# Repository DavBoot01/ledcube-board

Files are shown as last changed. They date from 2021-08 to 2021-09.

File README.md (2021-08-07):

# ledcube8x8x8-board

This is a Kicad project for a Led Cube 8x8x8 controller board.

### Tags

- FPGA/CPLD
- ESP32
- Led controller

### Used Library and Footprint

- DigiKey: https://github.com/Digi-Key/digikey-kicad-library
- LM1085: https://app.ultralibrarian.com/details/15DE1302-103F-11E9-AB3A-0A3560A4CCCC/Texas-Instruments/LM1085IS-12-NOPB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
- SN74LVCC3245APWR: https://www.snapeda.com/parts/SN74LVCC3245APWR/TEXAS%20INSTRUMENTS%20(VA)/view-part/?ref=digikey
- B8B-PH-SM4-TB: https://www.snapeda.com/parts/B8B-PH-SM4-TB(LF)(SN)/JST%20Sales/view-part/?ref=digikey
- ESP32-DEVKITC-32D: https://www.snapeda.com/parts/ESP32-DEVKITC-32D/Espressif%20Systems/view-part/
- (SLOT uSD) WM6357CT-ND: https://www.snapeda.com/parts/104031-0811/Molex/view-part/?ref=digikey
- IP4220CZ6F: https://www.snapeda.com/parts/IP4220CZ6/NXP%20Semiconductors/view-part/?ref=digikey

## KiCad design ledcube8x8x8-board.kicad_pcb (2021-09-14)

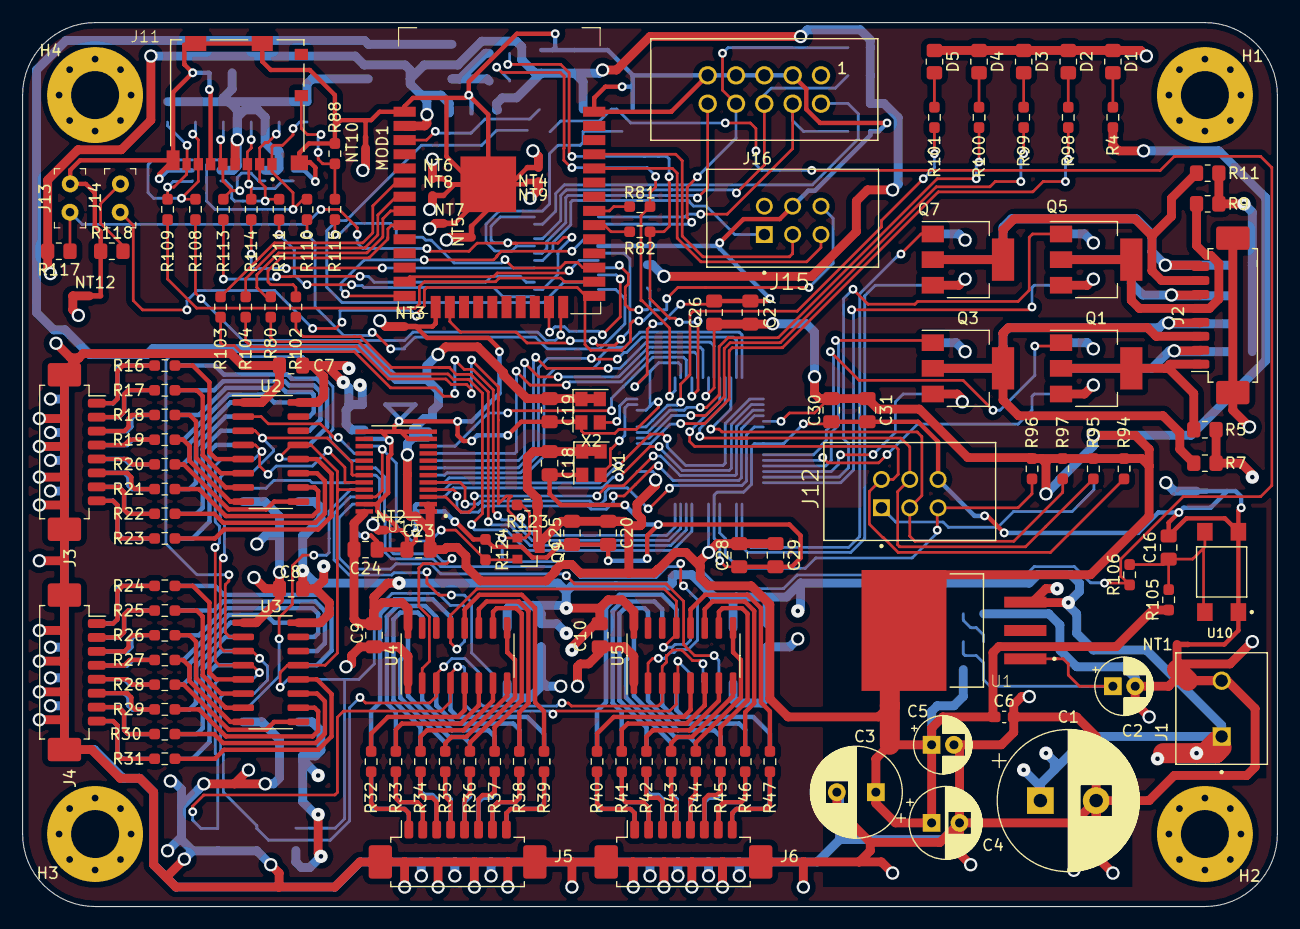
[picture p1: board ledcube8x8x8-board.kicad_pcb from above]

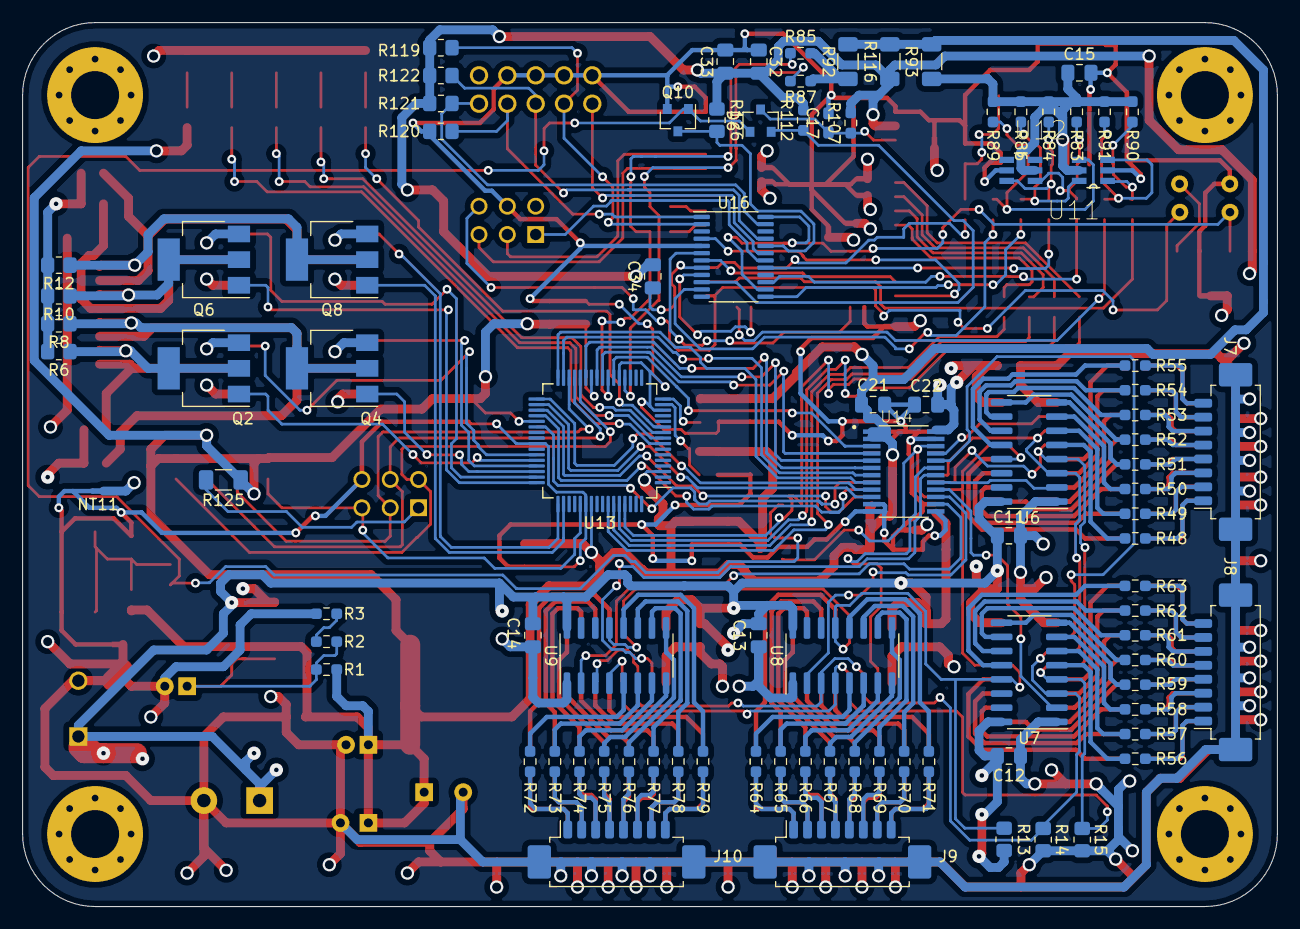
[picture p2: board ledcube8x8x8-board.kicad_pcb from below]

Board: 4 copper layers, 112.5 x 79.2 mm, 227 parts (92 on the bottom side), 239 nets.

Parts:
C1: 1000uF; CP_Radial_D12.5mm_P5.00mm
C2, C5: 10uF; CP_Radial_D5.0mm_P2.00mm
C3: 150uF; CP_Radial_D8.0mm_P3.50mm
C4: 100uF; CP_Radial_D6.3mm_P2.50mm
C6, C17: 1uF; C_0603_1608Metric_Pad1.08x0.95mm_HandSolder
C7, C8, C9, C10, C11, C12, C13, C14, C16, C21, C22, C23, C24, C28, C29, C30, C31, C32: 100nF; C_0805_2012Metric_Pad1.18x1.45mm_HandSolder
C15, C34: 4.7uF; C_0805_2012Metric_Pad1.18x1.45mm_HandSolder
C18, C19, C20, C25, C26, C27: 10nF; C_0805_2012Metric_Pad1.18x1.45mm_HandSolder
C33: 22uF; C_0805_2012Metric_Pad1.18x1.45mm_HandSolder
D1, D3: GREEN; R_0805_2012Metric_Pad1.20x1.40mm_HandSolder
D2: RED; R_0805_2012Metric_Pad1.20x1.40mm_HandSolder
D4, D5: ORANGE; R_0805_2012Metric_Pad1.20x1.40mm_HandSolder
D6: BAT54A; SOT-23
H1, H2, H3, H4: MountingHole_Pad; MountingHole_4.3mm_M4_Pad_Via
J1: 282836-2; CONN_282836-2
J2, J3, J4, J5, J6, J7, J8, J9, J10: molex_53261-0871; Molex_PicoBlade_53261-0871_1x08-1MP_P1.25mm_Horizontal
J11: 104031-0811; MOLEX_104031-0811
J12, J15: 30306-6002HB; 3M_30306-6002HB
J13, J14: hedear; PinHeader_1x2_P2.54mm
J16: 61201021621
MOD1: ESP32-WROOM-32; ESP32-WROOM-32D
NT1, NT2, NT3, NT4, NT5, NT6, NT7, NT8, NT9, NT10, NT11, NT12: Net-Tie_2; NetTie-2_SMD_Pad0.5mm
Q1, Q2, Q3, Q4, Q5, Q6, Q7, Q8: Q_NMOS_GDSD; SOT-223
Q9, Q10: Q_PMOS_GSD; SOT-23
R1: 121; R_0603_1608Metric_Pad0.98x0.95mm_HandSolder
R2: 42.2; R_0603_1608Metric_Pad0.98x0.95mm_HandSolder
R3: 56.2; R_0603_1608Metric_Pad0.98x0.95mm_HandSolder
R4, R98, R99, R100, R101: 1K; R_0603_1608Metric_Pad0.98x0.95mm_HandSolder
R5, R6, R7, R8, R9, R10, R11, R12, R13, R14, R15, R117, R118, R119, R120, R121, R122, R126: 10K; R_0805_2012Metric_Pad1.20x1.40mm_HandSolder
R16, R17, R18, R19, R20, R21, R22, R23, R24, R25, R26, R27, R28, R29, R30, R31, R32, R33, R34, R35, R36, R37, R38, R39, R40, R41, R42, R43, R44, R45, R46, R47, R48, R49, R50, R51, R52, R53, R54, R55, R56, R57, R58, R59, R60, R61, R62, R63, R64, R65, R66, R67, R68, R69, R70, R71, R72, R73, R74, R75, R76, R77, R78, R79: 100; R_0603_1608Metric_Pad0.98x0.95mm_HandSolder
R80, R81, R82, R102, R103, R104, R106, R108, R109, R110, R111, R113, R114, R115: 0R; R_0603_1608Metric_Pad0.98x0.95mm_HandSolder
R83, R84, R86, R88, R89, R90, R91, R94, R95, R96, R97, R105, R107, R123, R124: 10K; R_0603_1608Metric_Pad0.98x0.95mm_HandSolder
R85, R87: 2K7; R_0603_1608Metric_Pad0.98x0.95mm_HandSolder
R92, R93, R116, R125: 0R; R_1206_3216Metric_Pad1.30x1.75mm_HandSolder
R112: 47K; R_0603_1608Metric_Pad0.98x0.95mm_HandSolder
U1: LM1085IS-12; TO254P1524X483-4N
U2, U3, U4, U5, U6, U7, U8, U9: STP08CP05MTR; SOIC-16_3.9x9.9mm_P1.27mm
U10: TL3305AF260QG; SW_TL3305AF260QG
U11, U12: IP4220CZ6; SOT95P275X110-6N
U13: XC9572XL-VQ64; TQFP-64_10x10mm_P0.5mm
U14, U15: SN74LVCC3245APWR; SOP65P640X120-24N
U16: TS3A27518EPW; TSSOP-24_4.4x7.8mm_P0.65mm
X1: ASE-40MHz; Oscillator_SMD_Abracon_ASE-4Pin_3.2x2.5mm
X2: ASE-25MHz; Oscillator_SMD_Abracon_ASE-4Pin_3.2x2.5mm

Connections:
/DATA_LED1: U2.2, U14.21
/DATA_LED2: U3.2, U14.20
/DATA_LED3: U4.2, U14.19
/DATA_LED4: U5.2, U14.18
/DATA_LED5: U6.2, U14.17
/DATA_LED6: U7.2, U14.16
/DATA_LED7: U8.2, U14.15
/DATA_LED8: U9.2, U14.14
/LAYER_SEL1: Q1.1, U13.43
/LAYER_SEL2: Q2.1, U13.44
/LAYER_SEL3: Q3.1, U13.45
/LAYER_SEL4: Q4.1, U13.46
/LAYER_SEL5: Q5.1, U13.47
/LAYER_SEL6: Q6.1, U13.48
/LAYER_SEL7: Q7.1, U13.49
/LAYER_SEL8: Q8.1, U13.50
/VCC_3V3: C3.1, C4.1, C5.1, C6.1, C18.1, C19.1, C20.1, C21.2, C23.2, C25.1, C26.1, C27.1, C28.1, C29.1, C30.1, C31.1, Q9.3, R1.1, R4.1, R92.2, R93.2, R94.1, R95.1, R96.1, R97.1, R105.1, R116.2, R123.1, R125.1, U1.4, U13.3, U13.26, U13.37, U13.55, U14.1, U14.2, U15.1, U15.2, X1.1, X1.4, X2.1, X2.4
/VCC_5V0: C1.1, C7.1, C8.1, C9.1, C10.1, C11.1, C12.1, C13.1, C14.1, C22.2, C24.2, J1.1, R5.2, R6.2, R7.2, R8.2, R9.2, R10.2, R11.2, R12.2, R13.1, U1.3, U2.16, U3.16, U4.16, U5.16, U6.16, U7.16, U8.16, U9.16, U14.24, U15.24
/layer_led_mux.sch/CLK: R14.1, U2.3, U3.3, U4.3, U5.3, U6.3, U7.3, U8.3, U9.3, U15.19
/layer_selector.sch/LAYER_SEL1: J2.1, Q1.2, Q1.4, R5.1
/layer_selector.sch/LAYER_SEL2: J2.2, Q2.2, Q2.4, R6.1
/layer_selector.sch/LAYER_SEL3: J2.3, Q3.2, Q3.4, R7.1
/layer_selector.sch/LAYER_SEL4: J2.4, Q4.2, Q4.4, R8.1
/layer_selector.sch/LAYER_SEL5: J2.5, Q5.2, Q5.4, R9.1
/layer_selector.sch/LAYER_SEL6: J2.6, Q6.2, Q6.4, R10.1
/layer_selector.sch/LAYER_SEL7: J2.7, Q7.2, Q7.4, R11.1
/layer_selector.sch/LAYER_SEL8: J2.8, Q8.2, Q8.4, R12.1
/pl.sch/CLK_25M: U13.16, X2.3
/pl.sch/CLK_40M: U13.15, X1.3
/pl.sch/DATA_CLK_3V3: U13.38, U15.5
/pl.sch/DATA_LE_3V3: U13.36, U15.4
/pl.sch/DATA_LE_5V0: R15.1, U2.4, U3.4, U4.4, U5.4, U6.4, U7.4, U8.4, U9.4, U15.20
/pl.sch/DATA_ROW1_3V3: U13.22, U14.3
/pl.sch/DATA_ROW2_3V3: U13.24, U14.4
/pl.sch/DATA_ROW3_3V3: U13.25, U14.5
/pl.sch/DATA_ROW4_3V3: U13.27, U14.6
/pl.sch/DATA_ROW5_3V3: U13.31, U14.7
/pl.sch/DATA_ROW6_3V3: U13.32, U14.8
/pl.sch/DATA_ROW7_3V3: U13.33, U14.9
/pl.sch/DATA_ROW8_3V3: U13.34, U14.10
/pl.sch/GPIO0: R80.1, U13.58
/pl.sch/GPIO1: R102.1, U13.59
/pl.sch/GPIO2: R103.1, U13.60
/pl.sch/GPIO3: R104.1, U13.61
/pl.sch/I2C_SCL: R81.1, R87.2, U13.20
/pl.sch/I2C_SDA: R82.1, R85.2, U13.23
/pl.sch/LED_G: R99.1, U13.9
/pl.sch/LED_O1: R100.1, U13.10
/pl.sch/LED_O2: R101.1, U13.11
/pl.sch/LED_R: R98.1, U13.8
/pl.sch/TCK: J12.3, R97.2, U13.30
/pl.sch/TDI: J12.2, R94.2, U13.28
/pl.sch/TDO: J12.5, R96.2, U13.53
/pl.sch/TMS: J12.4, R95.2, U13.29
/pl.sch/~DATA_OE_3V3: U13.35, U15.3
/pl.sch/~DATA_OE_5V0: R13.2, U2.13, U3.13, U4.13, U5.13, U6.13, U7.13, U8.13, U9.13, U15.21
/pl.sch/~OE: Q9.2, R124.1, U14.22, U15.22
/pl.sch/~SYS_RST: D6.1, Q9.1, Q10.1, R106.1, R123.2
/ps.sch/ESP_GPIO0: MOD1.8, R80.2
/ps.sch/ESP_GPIO1: MOD1.9, R102.2
/ps.sch/ESP_GPIO2: MOD1.6, R103.2
/ps.sch/ESP_GPIO3: MOD1.7, R104.2
/ps.sch/ESP_I2C_SCL: MOD1.31, R81.2
/ps.sch/ESP_I2C_SDA: MOD1.30, R82.2
/ps.sch/ESP_PU: C17.1, D6.3, MOD1.3, R107.2
/ps.sch/GPIO0: J14.1, J15.6, MOD1.25
/ps.sch/MTCK_SDDATA3: MOD1.16, U16.6
/ps.sch/MTDI_SDDATA2: MOD1.14, U16.4
/ps.sch/MTDO_SDCMD: MOD1.23, U16.9
/ps.sch/MTMS_SDCLK: MOD1.13, U16.7
/ps.sch/MUX_SEL_PRG: J13.1, R117.1, U16.14, U16.24
/ps.sch/PREST: J15.1, U16.18
/ps.sch/PRG_REST: D6.2, R112.2, U16.10
/ps.sch/R_nTRST: J16.10, U16.19
/ps.sch/SDDATA0: MOD1.24, R108.2
/ps.sch/SDDATA1: MOD1.26, R109.2
/ps.sch/SD_CD: MOD1.27, R115.1
/ps.sch/SD_CLK: R113.1, U16.15
/ps.sch/SD_CMD: R114.1, U16.17
/ps.sch/SD_DAT2: R110.2, U16.11
/ps.sch/SD_DAT3: R111.2, U16.13
/ps.sch/TCK: J16.4, R120.2, U16.1
/ps.sch/TDI: J16.8, R119.2, U16.2
/ps.sch/TDO: J16.6, R122.2, U16.21
/ps.sch/TMS: J16.2, R121.2, U16.23
/ps.sch/U0RXD: J15.5, MOD1.34
/ps.sch/U0TXD: J15.3, MOD1.35
ESP_3V3: C32.1, C33.1, C34.2, MOD1.2, R107.1, R112.1, R116.1, R117.2, R119.1, R121.1, R122.1, R126.2
GND: C1.2, C2.2, C3.2, C4.2, C5.2, C6.2, C7.2, C8.2, C9.2, C10.2, C11.2, C12.2, C13.2, C14.2, D1.1, D2.1, D3.1, D4.1, D5.1, H1.1, H2.1, H3.1, H4.1, J1.2, J2.MP, J3.MP, J4.MP, J5.MP, J6.MP, J7.MP, J8.MP, J9.MP, J10.MP, NT1.1, NT2.1, NT3.1, NT4.1, NT5.1, NT6.1, NT7.1, NT8.1, NT9.1, NT10.1, NT11.1, NT12.1, Q1.3, Q2.3, Q3.3, Q4.3, Q5.3, Q6.3, Q7.3, Q8.3, R3.2, R14.2, R15.2, U2.1, U3.1, U4.1, U5.1, U6.1, U7.1, U8.1, U9.1
GNDD: C15.2, C16.2, C17.2, C18.2, C19.2, C20.2, C21.1, C22.1, C23.1, C24.1, C25.2, C26.2, C27.2, C28.2, C29.2, C30.2, C31.2, C32.2, C33.2, J11.6, J11.G1, J11.G2, J11.G3, J11.G4, J12.6, J13.2, J15.4, J16.3, J16.5, J16.7, J16.9, MOD1.1, MOD1.15, MOD1.38, MOD1.39, NT1.2, NT2.2, NT3.2, NT4.2, NT5.2, NT6.2, NT7.2, NT8.2, NT9.2, NT10.2, NT11.2, NT12.2, Q10.2, R88.2, R118.1, R120.1, R124.2, U10.1, U10.2, U11.2, U12.2, U13.14, U13.21, U13.41, U13.54, U14.11, U14.12, U14.13, U14.23, U15.11, U15.12, U15.13, U15.23, U16.5, X1.2, X2.2
I2C_3V3: R85.1, R87.1, R92.1
unnamed: C2.1, R1.2, R2.1, U1.1
unnamed: C16.1, R105.2, R106.2, U10.3, U10.4
unnamed: C34.1, U16.8
unnamed: D1.2, R4.2
unnamed: D2.2, R98.2
unnamed: D3.2, R99.2
unnamed: D4.2, R100.2
unnamed: D5.2, R101.2
unnamed: J3.1, R16.1
unnamed: J3.2, R17.1
unnamed: J3.3, R18.1
unnamed: J3.4, R19.1
unnamed: J3.5, R20.1
unnamed: J3.6, R21.1
unnamed: J3.7, R22.1
unnamed: J3.8, R23.1
unnamed: J4.1, R24.1
unnamed: J4.2, R25.1
unnamed: J4.3, R26.1
unnamed: J4.4, R27.1
unnamed: J4.5, R28.1
unnamed: J4.6, R29.1
unnamed: J4.7, R30.1
unnamed: J4.8, R31.1
unnamed: J5.1, R32.1
unnamed: J5.2, R33.1
unnamed: J5.3, R34.1
unnamed: J5.4, R35.1
unnamed: J5.5, R36.1
unnamed: J5.6, R37.1
unnamed: J5.7, R38.1
unnamed: J5.8, R39.1
unnamed: J6.1, R40.1
unnamed: J6.2, R41.1
unnamed: J6.3, R42.1
unnamed: J6.4, R43.1
unnamed: J6.5, R44.1
unnamed: J6.6, R45.1
unnamed: J6.7, R46.1
unnamed: J6.8, R47.1
unnamed: J7.1, R48.1
unnamed: J7.2, R49.1
unnamed: J7.3, R50.1
unnamed: J7.4, R51.1
unnamed: J7.5, R52.1
unnamed: J7.6, R53.1
unnamed: J7.7, R54.1
unnamed: J7.8, R55.1
unnamed: J8.1, R56.1
unnamed: J8.2, R57.1
unnamed: J8.3, R58.1
unnamed: J8.4, R59.1
unnamed: J8.5, R60.1
unnamed: J8.6, R61.1
unnamed: J8.7, R62.1
unnamed: J8.8, R63.1
unnamed: J9.1, R64.1
unnamed: J9.2, R65.1
unnamed: J9.3, R66.1
unnamed: J9.4, R67.1
unnamed: J9.5, R68.1
unnamed: J9.6, R69.1
unnamed: J9.7, R70.1
unnamed: J9.8, R71.1
unnamed: J10.1, R72.1
unnamed: J10.2, R73.1
unnamed: J10.3, R74.1
unnamed: J10.4, R75.1
unnamed: J10.5, R76.1
unnamed: J10.6, R77.1
unnamed: J10.7, R78.1
unnamed: J10.8, R79.1
unnamed: J11.1, R89.2, R110.1, U11.4
unnamed: J11.2, R86.2, R111.1, U11.6
unnamed: J11.3, R84.2, R114.2, U12.3
unnamed: J11.5, R83.2, R113.2, U12.4
unnamed: J11.7, R91.2, R108.1, U11.3
unnamed: J11.8, R90.2, R109.1, U11.1
unnamed: J11.9, R88.1, R115.2
unnamed: J12.1, R125.2
unnamed: J14.2, R118.2
unnamed: Q10.3, R126.1, U16.20
unnamed: R2.2, R3.1
unnamed: R16.2, U2.5
unnamed: R17.2, U2.6
unnamed: R18.2, U2.7
unnamed: R19.2, U2.8
unnamed: R20.2, U2.9
unnamed: R21.2, U2.10
unnamed: R22.2, U2.11
unnamed: R23.2, U2.12
unnamed: R24.2, U3.5
unnamed: R25.2, U3.6
unnamed: R26.2, U3.7
unnamed: R27.2, U3.8
unnamed: R28.2, U3.9
unnamed: R29.2, U3.10
unnamed: R30.2, U3.11
unnamed: R31.2, U3.12
unnamed: R32.2, U4.5
unnamed: R33.2, U4.6
unnamed: R34.2, U4.7
unnamed: R35.2, U4.8
unnamed: R36.2, U4.9
unnamed: R37.2, U4.10
unnamed: R38.2, U4.11
unnamed: R39.2, U4.12
unnamed: R40.2, U5.5
unnamed: R41.2, U5.6
unnamed: R42.2, U5.7
unnamed: R43.2, U5.8
unnamed: R44.2, U5.9
unnamed: R45.2, U5.10
unnamed: R46.2, U5.11
unnamed: R47.2, U5.12
unnamed: R48.2, U6.5
unnamed: R49.2, U6.6
unnamed: R50.2, U6.7
unnamed: R51.2, U6.8
unnamed: R52.2, U6.9
unnamed: R53.2, U6.10
unnamed: R54.2, U6.11
unnamed: R55.2, U6.12
unnamed: R56.2, U7.5
unnamed: R57.2, U7.6
unnamed: R58.2, U7.7
unnamed: R59.2, U7.8
unnamed: R60.2, U7.9
unnamed: R61.2, U7.10
unnamed: R62.2, U7.11
unnamed: R63.2, U7.12
unnamed: R64.2, U8.5
unnamed: R65.2, U8.6
unnamed: R66.2, U8.7
unnamed: R67.2, U8.8
unnamed: R68.2, U8.9
unnamed: R69.2, U8.10
unnamed: R70.2, U8.11
unnamed: R71.2, U8.12
unnamed: R72.2, U9.5
unnamed: R73.2, U9.6
unnamed: R74.2, U9.7
unnamed: R75.2, U9.8
unnamed: R76.2, U9.9
unnamed: R77.2, U9.10
unnamed: R78.2, U9.11
unnamed: R79.2, U9.12
SD_3V3: C15.1, J11.4, R83.1, R84.1, R86.1, R89.1, R90.1, R91.1, R93.1, U11.5, U12.5

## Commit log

2021-04-05 KiCad empty project
    [ledcube-board.kicad_pcb, ledcube-board.sch]
2021-04-05 Add power supply schematic part
    Input: 5V
    Output: 3.3V
    Used a PMIC Lineary regulator voltage (LM1085IS)
    [ledcube-board.sch, power_supply.sch]
2021-04-06 Add programmable logic (pl) schematic part
    Use a Xilinx's CPLD: XC9572XL-VQ64
    The board provides:
    - JTAG interface for this CPLD;
    - two CPLD's input source clocks @ 40MHz and 25MHz.
    Main function: Manage all signals of the cube, included the timing.
    [ledcube-board.sch, pl.sch, power_supply.sch]
2021-04-06 Add layer selector schematic part
    Main function: is a common sink for the GND for all layers of the
    cube. Is like a multiplexer that the PL part drives properly so
    that only one layer at a time is connected to GND.
    [layer_selector.sch, ledcube-board.sch, pl.sch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]
2021-04-06 Add layer led muxing schematic part
    Main funcion: also this part is driven by the CPLD. This part of
    schematic has 64 output (one for each led of each layers - to
    remember that all leds in a single column are connect togheter
    through the anode - ). In this way all 64 leds can be driven
    with 11 signal from CPLD (8 for data and 3 for control) instead of
    64.
    [layer_led_mux.sch, layer_selector.sch, ledcube-board.sch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]
2021-04-06 Add microcontroller (ps) schematic part
    This part is compatible with the external board ESP32-DEVKITC-32D.
    The ESP32 microcontroller is connected to CPLD via I2C bus and some
    other GPIOs signal. Moreover, on board there is also a uSD card slot
    connected to the ESP32.
    External reference:
    - https://docs.espressif.com/projects/esp-idf/en/latest/esp32/hw-reference/esp32/get-started-devkitc.html
    [layer_led_mux.sch, layer_selector.sch, ledcube-board.sch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]
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2021-04-07 Export of all pin sheet
    [ledcube-board.sch]
2021-04-07 Connect all macro blocks
    [ledcube-board.sch]
2021-04-07 Fix bug on bus's linking
    [layer_led_mux.sch, layer_selector.sch, ledcube-board.sch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]
2021-04-07 Remove resistor on 3.3V of ESP connector in order to avoid a warning
    [ps.sch]
2021-04-07 Add four mounting hole pads
    [ledcube-board.sch]
2021-04-08 Add four GPIOs between PL and PS
    [ledcube-board.sch, pl.sch, ps.sch]
2021-04-17 Chage vertical connector with molex horizontal connector
    [layer_led_mux.sch, layer_selector.sch, ledcube-board.sch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]
2021-04-17 Update schematic with newest molex connector into external library
    [layer_led_mux.sch, layer_selector.sch, pl.sch]
2021-04-17 PCB: relative placement of connectors for row maagement
    [ledcube-board.kicad_pcb]
2021-04-17 PCB: routing for connectors J3...J10
    [ledcube-board.kicad_pcb]
2021-04-18 Complete routing of single part of led connectors
    [ledcube-board.kicad_pcb]
2021-04-18 Schematic: Change uSD connector (now is a Molex one)
    [ledcube-board.kicad_pcb, ps.sch]
2021-04-18 Schematic: Fix connection error
    [layer_led_mux.sch]
2021-04-20 PCB: partial routing of CPLD part
    [ledcube-board.kicad_pcb]
2021-04-22 PCB: Placement of all top layer
    [ledcube-board.kicad_pcb]
2021-04-22 PCB: Resize of some net of layer selector part
    [ledcube-board.kicad_pcb]
2021-04-24 PCB: Placement @ 95%
    [ledcube-board.kicad_pcb]
2021-04-24 Change footprint from 0805 to 1206 of resistors that connect I2C_3V3 and SD_3V3 to source
    [ledcube-board.kicad_pcb, ps.sch]
2021-04-24 Chnage line for SD protection
    [ledcube-board.kicad_pcb, ps.sch]
2021-04-24 Connect SD_CD to IO5 of ESP32
    [ps.sch]
2021-04-24 PCB: Placement @ 98%
    [ledcube-board.kicad_pcb]
2021-04-25 PCB: Place all components
    [ledcube-board.kicad_pcb, ps.sch]
2021-05-02 PCB: complete placement
    [ledcube-board.kicad_pcb]
2021-06-06 Complete PCB placement and routing
    [ledcube-board.kicad_pcb, ledcube-board.sch, pl.sch]
2021-07-02 Update PCB traces
    [ledcube-board.kicad_pcb]
2021-08-07 Renamed projet into ledcube8x8x8-board
    [ledcube8x8x8-board.kicad_pcb, ledcube8x8x8-board.sch]
2021-08-07 Remove old file
    [ledcube-board.kicad_pcb, ledcube-board.sch]
2021-08-07 Change PL part: replaced ESP32 DevKit socket with ESP32 module
    The idea is to use directly the ESP32 without any addon or
    extra module to plug on the ledcube board. In this way the board
    is complete itself.
    Also a global reset button has been placed.
    [ledcube8x8x8-board.sch, pl.sch, power_supply.sch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]
2021-08-08 Update footprints
    [layer_led_mux.sch, layer_selector.sch, ledcube8x8x8-board.kicad_pcb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]
2021-08-08 Start with newest PCB routing
    [ledcube8x8x8-board.kicad_pcb]
2021-08-08 Relative placement of layer multiplexing
    [ledcube8x8x8-board.kicad_pcb]
2021-08-09 CHange CPLD's JTAG connector with a pin header
    [ledcube8x8x8-board.sch, pl.sch]
2021-08-09 Change power connector with a Wire-to-Board one
    [power_supply.sch]
2021-08-09 Change C1,C2,C3,C4,C5 capatictors with a THT type
    [power_supply.sch]
2021-08-09 Correct some net's labels
    [ledcube8x8x8-board.sch, pl.sch]
2021-08-09 Fix net of CMD/CLD signal of uSD of PS
    [ps.sch]
2021-08-09 Fix power rail of uSD card reader
    [ps.sch]
2021-08-11 PCB: Place some macro blocks
    [ledcube8x8x8-board.kicad_pcb]
2021-08-13 Place whole PS part. Start with PL one.
    [ledcube8x8x8-board.kicad_pcb, ledcube8x8x8-board.sch, ps.sch]
2021-08-13 PCB: Re-work routing of led multiplexer part
    [ledcube8x8x8-board.kicad_pcb]
2021-08-14 PCB: Re-work routing of PS part (now complete)
    [ledcube8x8x8-board.kicad_pcb, ledcube8x8x8-board.sch, power_supply.sch]
2021-08-14 PCB: Place led layer multiplexer
    [ledcube8x8x8-board.kicad_pcb]
2021-09-14 PCB complete
    [ledcube8x8x8-board.kicad_pcb, ledcube8x8x8-board.sch, power_supply.sch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]
